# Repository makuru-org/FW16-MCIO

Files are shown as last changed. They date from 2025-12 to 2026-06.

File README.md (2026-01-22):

<!--
# Usecase
This is the source files needed to easily create an Framework 16 to MCIO expansion bay, so one can add a external GPU to the FW 16.
# PCB Render
![](images/pcb.png)
# Schematics
![](/images/schematics.png)

# How to use
1. Order PCB by JLCPCB with the correct impedence matching. (pls create issue if confused or help needed)
2. Order ADT-link's MCIO to PCIe eGPU station with MCIO cable. (tested with F37C version)
3. Print repo's STD files with a 3D printer.

# License
My changes are licensed under: [https://cern-ohl.web.cern.ch/](CERN-OHL-S).

The plain PCB template is I believe the https://github.com/jyancat/ExpansionBay under CC BY 4.0.

This is a fork of the [https://github.com/Terrails/FW16-OCuLink](Terrails), work as of writting this, it is not licensed, IE under **UNLICENSED**.
--!>
# STILL IN DEV

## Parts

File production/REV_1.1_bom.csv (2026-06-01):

Designator | Footprint | Quantity | Value | LCSC Part #
C1, C2, C4, C5 | C_Wurth_WCAP-CSGP-0201 | 4 | 0201_885012004001 | C20040658
C3 | C_Wurth_WCAP-CSGP-0402 | 1 | 0402_885012105020 | C6839882
EEPROM1 | SOP8_ROM | 1 | BR24L32F-WE2 | C253183
FAN1, FAN2 | AMPHENOL_F3311A7H121004E200 | 2 | F3311A7H121004E200 | C3169422
MCIO1 | AMPHENOL_G97R22312HR | 1 | G97R22312HR | C4499806
R1, R2 | R_Wurth_WRIS-RSKS-0402 | 2 | 0402_560112110088 | 560112110088
R10, R3, R4, R5, R6, R7, R8, R9 | R_Wurth_WRIS-RSKS-0402 | 8 | 0402_560112110001 | C22463254
U1 | VDFN8_NNC_MCH | 1 | SY75602ATWL-TR | C3613417

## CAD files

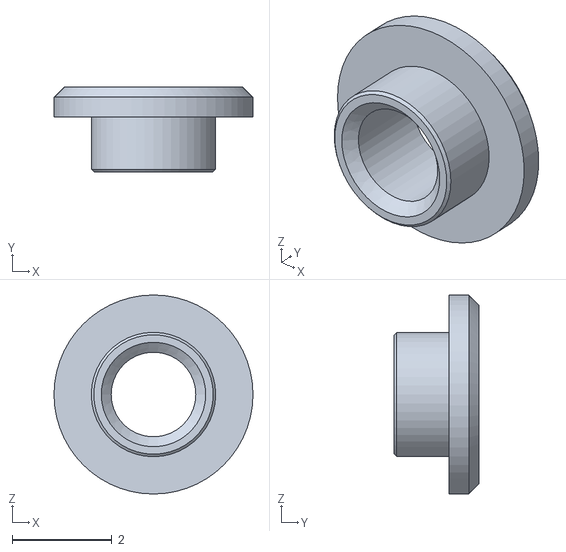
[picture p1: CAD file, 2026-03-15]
components/nut/Unnamed-IFGP6_UMA_IO_BOARD_ASM001SOLID004.obj
4.00 x 1.70 x 4.00

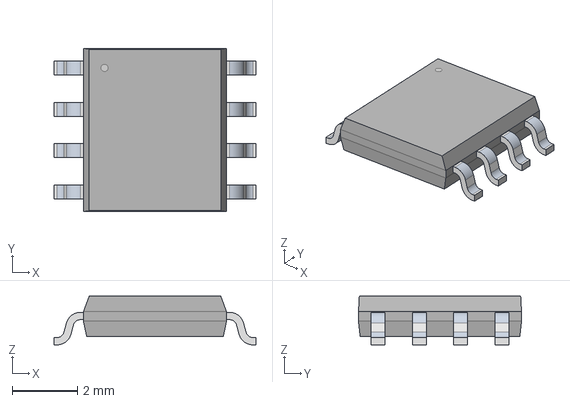
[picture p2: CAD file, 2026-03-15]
components/eeprom/SOP8_ROM.iges
6.20 x 5.00 x 1.50 mm

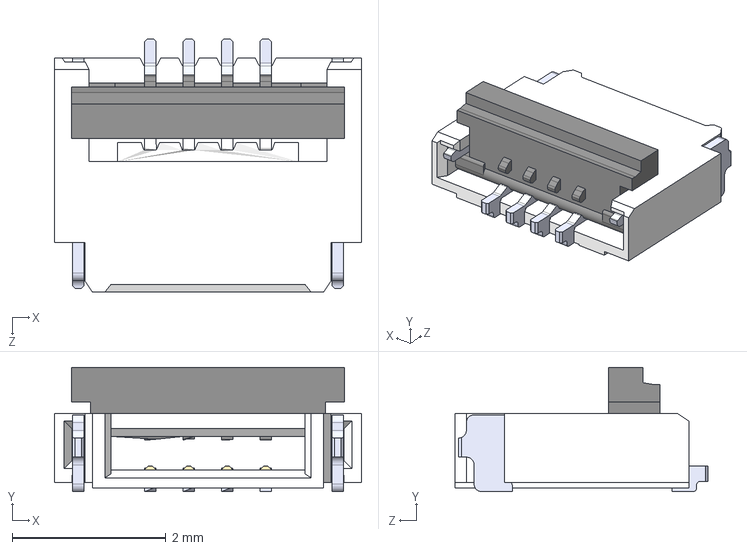
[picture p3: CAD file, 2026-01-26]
components/fan-connector/F3311A7H121004E200.step
4.00 x 1.62 x 3.30 mm

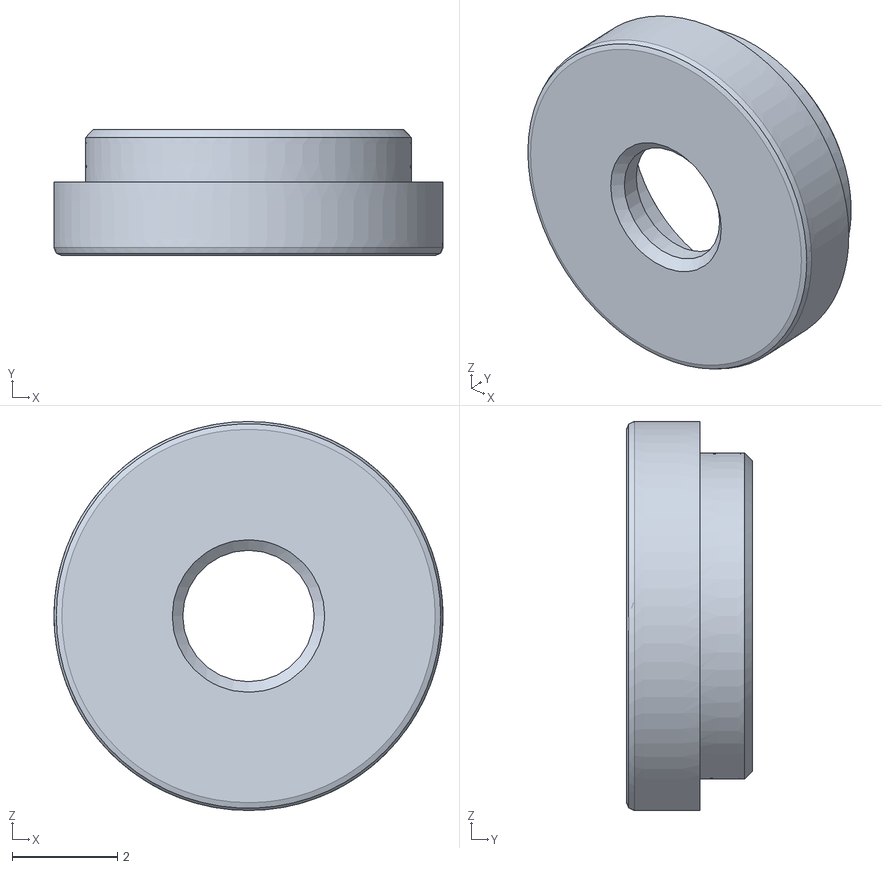
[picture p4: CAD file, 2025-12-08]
components/fw_expansion_bay_standoff_1_long.stl
7.40 x 2.40 x 7.40

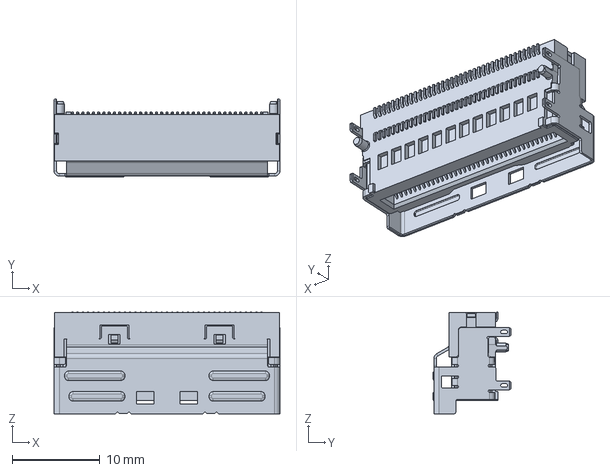
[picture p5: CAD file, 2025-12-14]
components/mcio-connector/G97R22312HR.step
25.8 x 8.94 x 11.6 mm

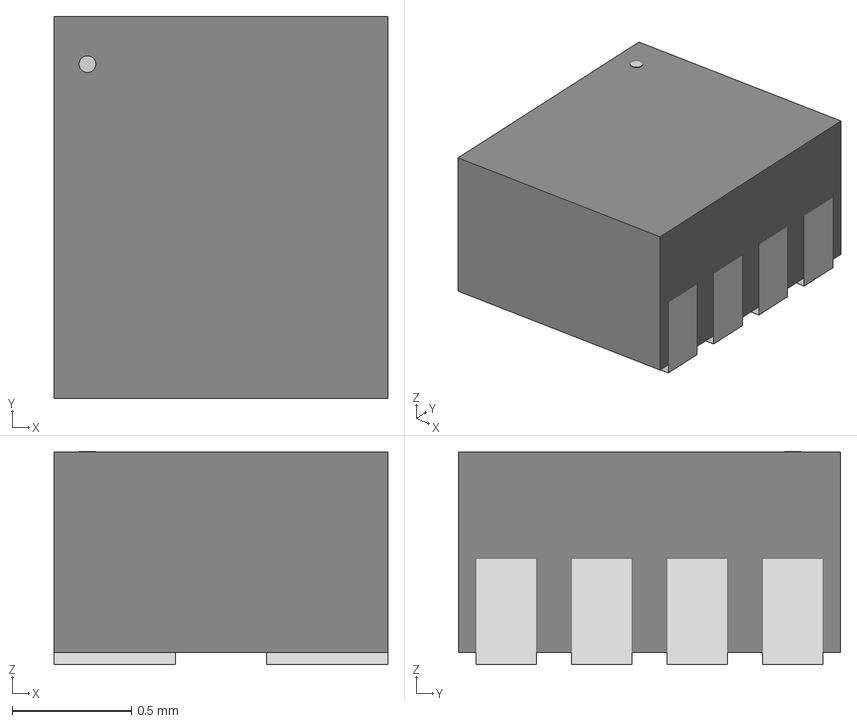
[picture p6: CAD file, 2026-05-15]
components/pcie-clk-buffer/VDFN8_NNC_MCH.iges
1.40 x 1.60 x 0.892 mm

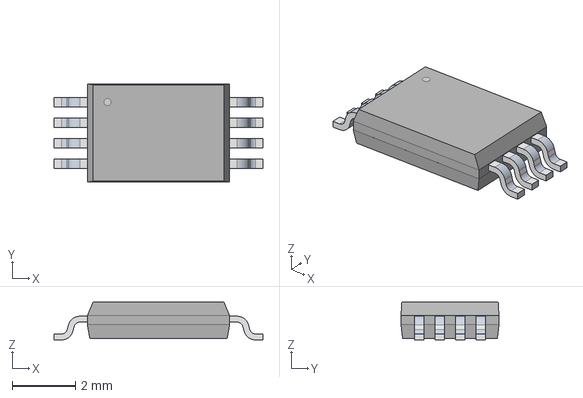
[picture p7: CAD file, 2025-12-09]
components/eeprom/TSSOP8_4P5X3P1X0P65_STM.iges
6.60 x 3.10 x 1.20 mm

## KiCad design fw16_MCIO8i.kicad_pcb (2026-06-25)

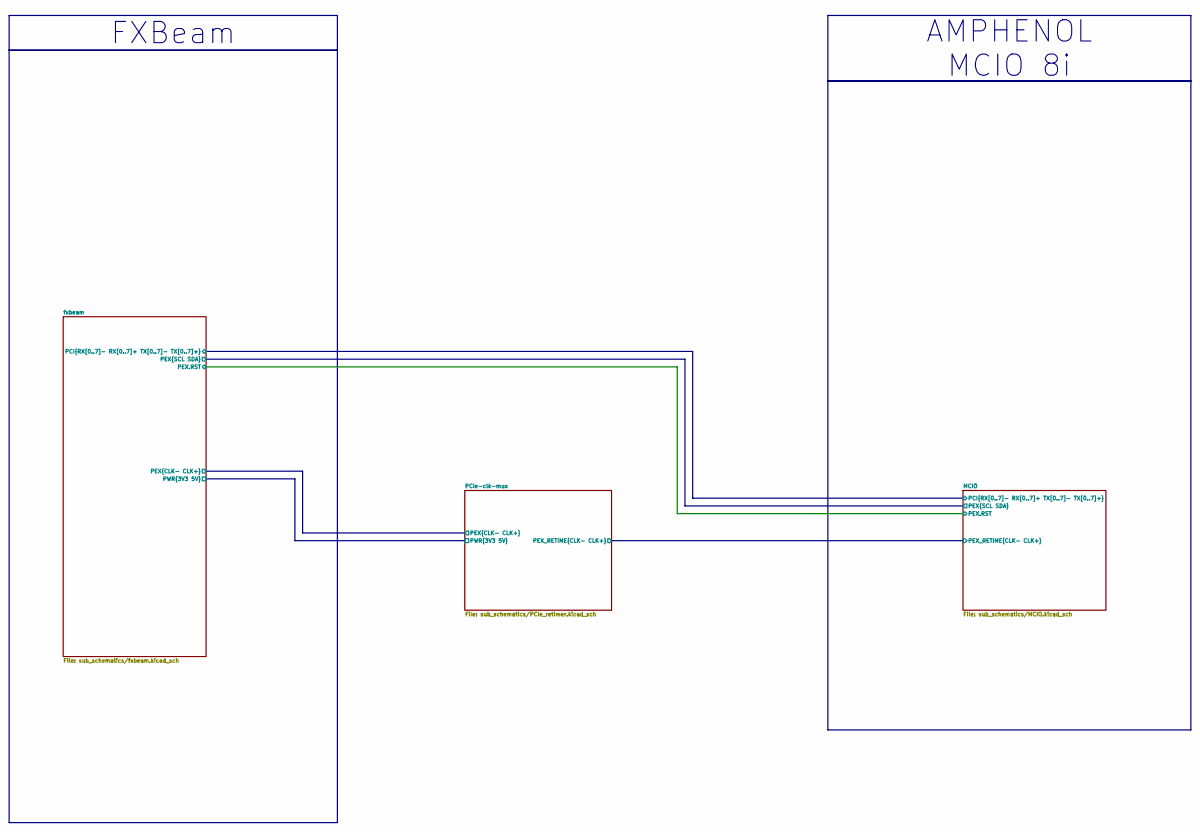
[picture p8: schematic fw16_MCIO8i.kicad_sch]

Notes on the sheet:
AMPHENOL MCIO 8i
FXBeam

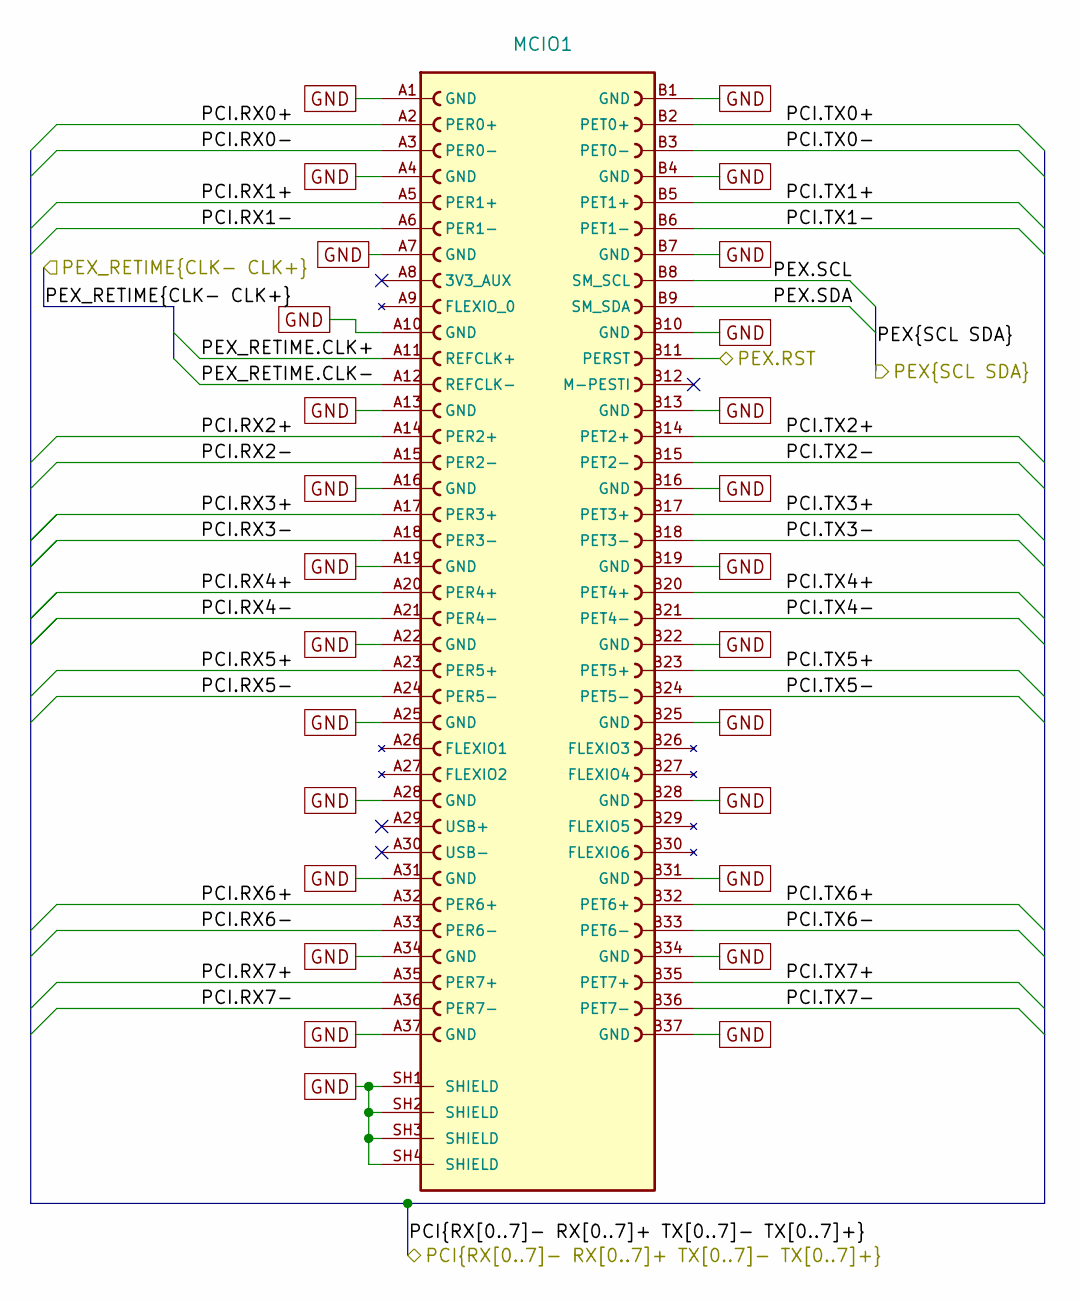
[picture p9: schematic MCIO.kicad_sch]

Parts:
MCIO1: G97R22312HR; AMPHENOL_G97R22312HR; PARTREV AX16; JLCPCB Part # C4499806

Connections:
/MCIO/PCI.RX0+: MCIO1.A2 (PER0+); also elsewhere on the board
/MCIO/PCI.RX0-: MCIO1.A3 (PER0-); also elsewhere on the board
/MCIO/PCI.RX1+: MCIO1.A5 (PER1+); also elsewhere on the board
/MCIO/PCI.RX1-: MCIO1.A6 (PER1-); also elsewhere on the board
/MCIO/PCI.RX2+: MCIO1.A14 (PER2+); also elsewhere on the board
/MCIO/PCI.RX2-: MCIO1.A15 (PER2-); also elsewhere on the board
/MCIO/PCI.RX3+: MCIO1.A17 (PER3+); also elsewhere on the board
/MCIO/PCI.RX3-: MCIO1.A18 (PER3-); also elsewhere on the board
/MCIO/PCI.RX4+: MCIO1.A20 (PER4+); also elsewhere on the board
/MCIO/PCI.RX4-: MCIO1.A21 (PER4-); also elsewhere on the board
/MCIO/PCI.RX5+: MCIO1.A23 (PER5+); also elsewhere on the board
/MCIO/PCI.RX5-: MCIO1.A24 (PER5-); also elsewhere on the board
/MCIO/PCI.RX6+: MCIO1.A32 (PER6+); also elsewhere on the board
/MCIO/PCI.RX6-: MCIO1.A33 (PER6-); also elsewhere on the board
/MCIO/PCI.RX7+: MCIO1.A35 (PER7+); also elsewhere on the board
/MCIO/PCI.RX7-: MCIO1.A36 (PER7-); also elsewhere on the board
/MCIO/PCI.TX0+: MCIO1.B2 (PET0+); also elsewhere on the board
/MCIO/PCI.TX0-: MCIO1.B3 (PET0-); also elsewhere on the board
/MCIO/PCI.TX1+: MCIO1.B5 (PET1+); also elsewhere on the board
/MCIO/PCI.TX1-: MCIO1.B6 (PET1-); also elsewhere on the board
/MCIO/PCI.TX2+: MCIO1.B14 (PET2+); also elsewhere on the board
/MCIO/PCI.TX2-: MCIO1.B15 (PET2-); also elsewhere on the board
/MCIO/PCI.TX3+: MCIO1.B17 (PET3+); also elsewhere on the board
/MCIO/PCI.TX3-: MCIO1.B18 (PET3-); also elsewhere on the board
/MCIO/PCI.TX4+: MCIO1.B20 (PET4+); also elsewhere on the board
/MCIO/PCI.TX4-: MCIO1.B21 (PET4-); also elsewhere on the board
/MCIO/PCI.TX5+: MCIO1.B23 (PET5+); also elsewhere on the board
/MCIO/PCI.TX5-: MCIO1.B24 (PET5-); also elsewhere on the board
/MCIO/PCI.TX6+: MCIO1.B32 (PET6+); also elsewhere on the board
/MCIO/PCI.TX6-: MCIO1.B33 (PET6-); also elsewhere on the board
/MCIO/PCI.TX7+: MCIO1.B35 (PET7+); also elsewhere on the board
/MCIO/PCI.TX7-: MCIO1.B36 (PET7-); also elsewhere on the board
/MCIO/PEX.SCL: MCIO1.B8 (SM_SCL); also elsewhere on the board
/MCIO/PEX.SDA: MCIO1.B9 (SM_SDA); also elsewhere on the board
/MCIO/PEX_RETIME.CLK+: MCIO1.A11 (REFCLK+); also elsewhere on the board
/MCIO/PEX_RETIME.CLK-: MCIO1.A12 (REFCLK-); also elsewhere on the board
/fxbeam/PEX.RST: MCIO1.B11 (PERST); also elsewhere on the board
GND: MCIO1.A1 (GND), MCIO1.A4 (GND), MCIO1.A7 (GND), MCIO1.A10 (GND), MCIO1.A13 (GND), MCIO1.A16 (GND), MCIO1.A19 (GND), MCIO1.A22 (GND), MCIO1.A25 (GND), MCIO1.A28 (GND), MCIO1.A31 (GND), MCIO1.A34 (GND), MCIO1.A37 (GND), MCIO1.B1 (GND), MCIO1.B4 (GND), MCIO1.B7 (GND), MCIO1.B10 (GND), MCIO1.B13 (GND), MCIO1.B16 (GND), MCIO1.B19 (GND), MCIO1.B22 (GND), MCIO1.B25 (GND), MCIO1.B28 (GND), MCIO1.B31 (GND), MCIO1.B34 (GND), MCIO1.B37 (GND), MCIO1.SH1 (SHIELD), MCIO1.SH2 (SHIELD), MCIO1.SH3 (SHIELD), MCIO1.SH4 (SHIELD); also elsewhere on the board

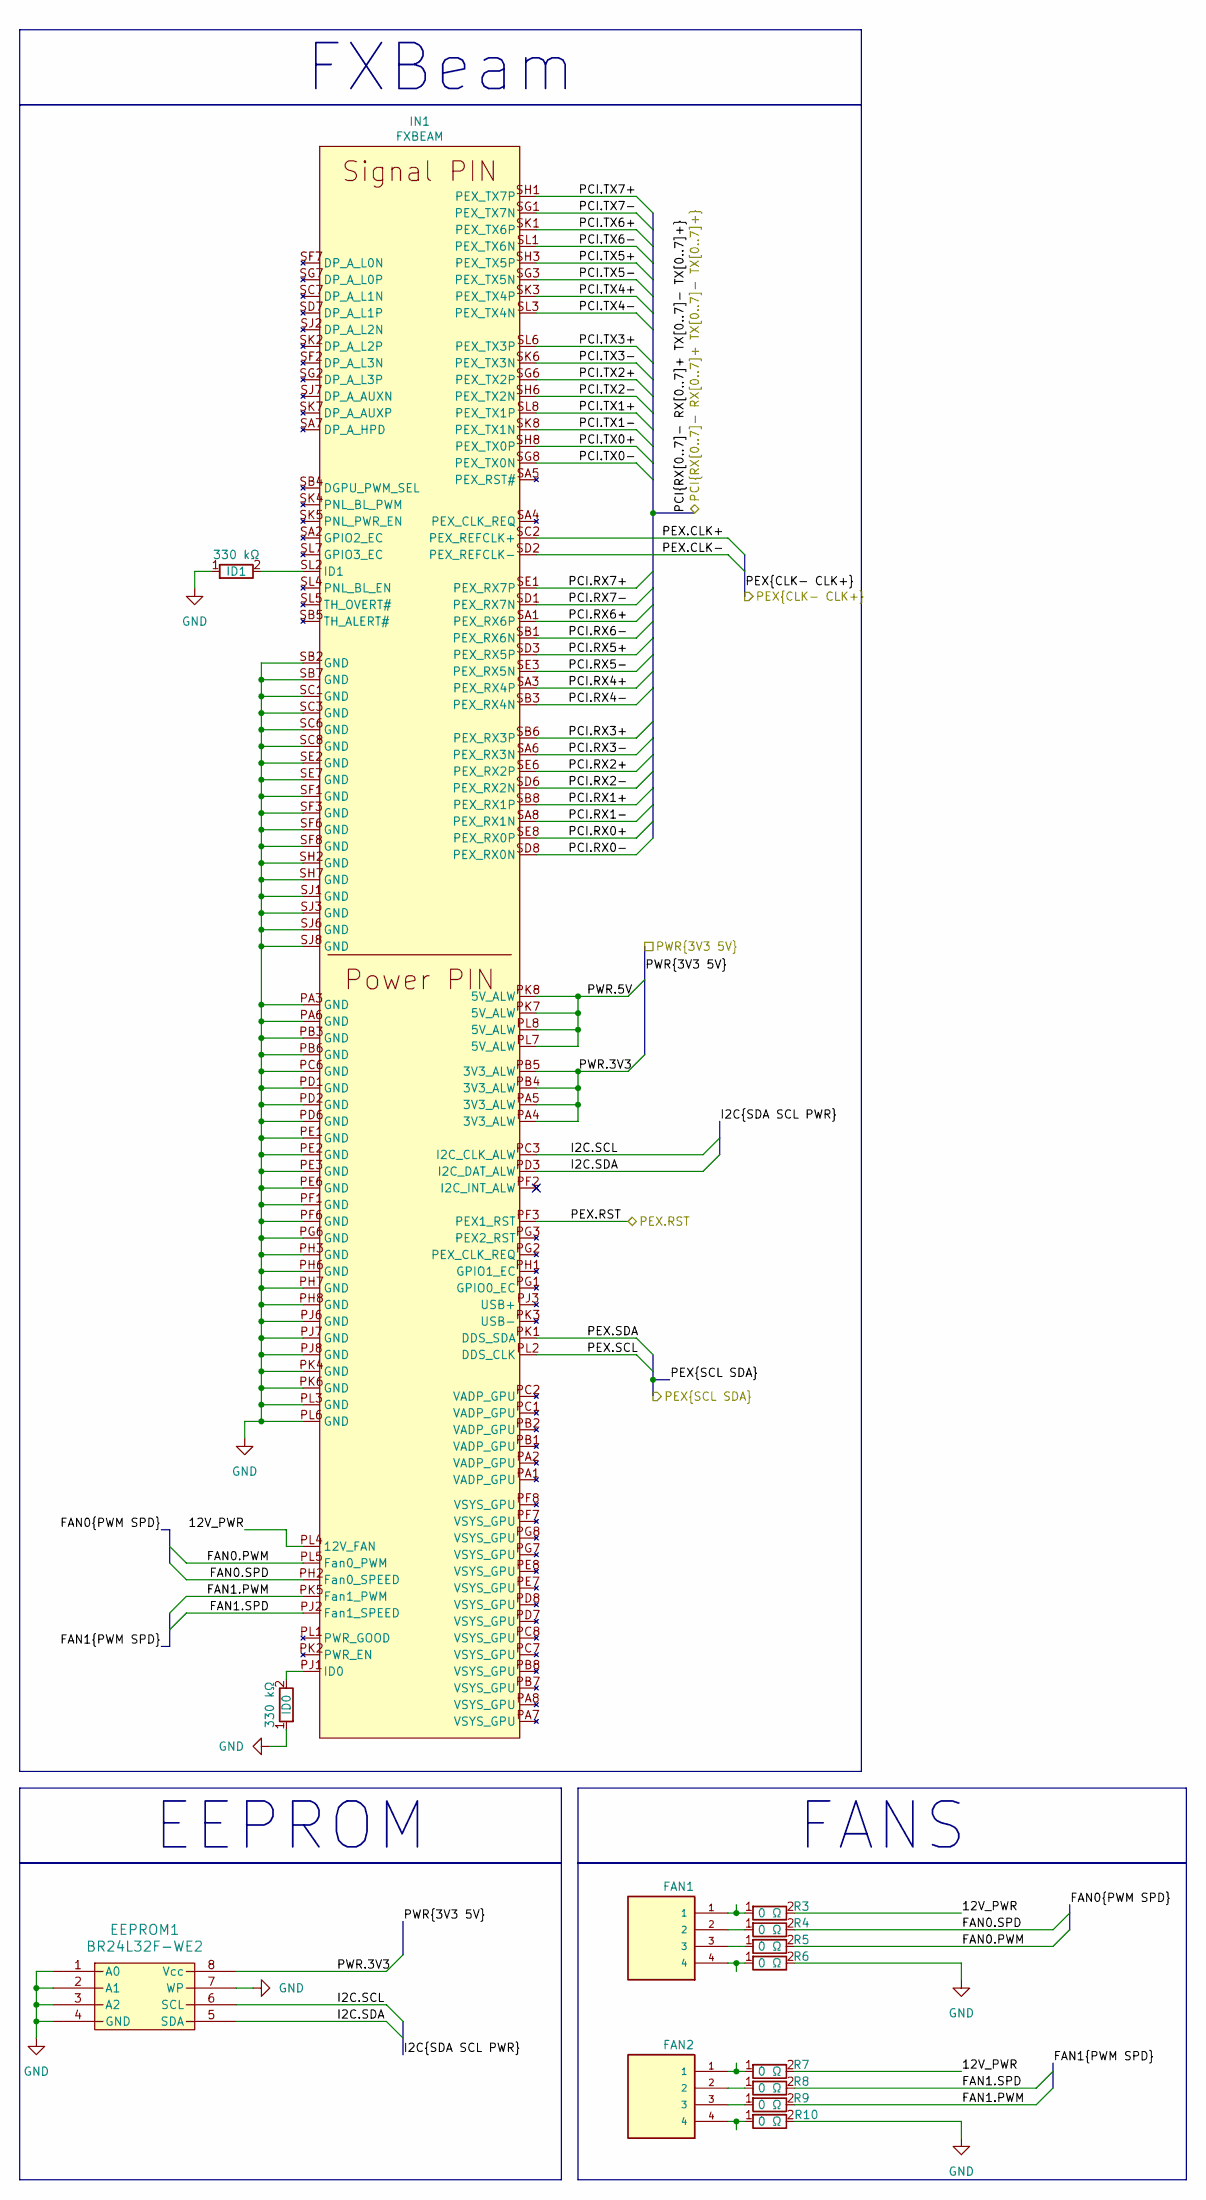
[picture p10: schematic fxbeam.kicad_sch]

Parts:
EEPROM1: BR24L32F-WE2; SOP8_ROM; MPN BR24L32F-WE2; JLCPCB Part # C253183
FAN1, FAN2: F3311A7H121004E200; AMPHENOL_F3311A7H121004E200; PARTREV A; JLCPCB Part # C3169422
ID0, ID1: 1206_R_560112132036; R_Wurth_WRIS-RSKS-1206_W; Part Number 560112132036; JLCPCB Part # C26798316
IN1: FXBEAM
R3, R4, R5, R6, R7, R8, R9, R10: 1206_R_560112132007; R_Wurth_WRIS-RSKS-1206_W; Part Number 560112132007; JLCPCB Part # C25268462

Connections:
/MCIO/PCI.RX0+: IN1.SE8 (PEX_RX0P); also elsewhere on the board
/MCIO/PCI.RX0-: IN1.SD8 (PEX_RX0N); also elsewhere on the board
/MCIO/PCI.RX1+: IN1.SB8 (PEX_RX1P); also elsewhere on the board
/MCIO/PCI.RX1-: IN1.SA8 (PEX_RX1N); also elsewhere on the board
/MCIO/PCI.RX2+: IN1.SE6 (PEX_RX2P); also elsewhere on the board
/MCIO/PCI.RX2-: IN1.SD6 (PEX_RX2N); also elsewhere on the board
/MCIO/PCI.RX3+: IN1.SB6 (PEX_RX3P); also elsewhere on the board
/MCIO/PCI.RX3-: IN1.SA6 (PEX_RX3N); also elsewhere on the board
/MCIO/PCI.RX4+: IN1.SA3 (PEX_RX4P); also elsewhere on the board
/MCIO/PCI.RX4-: IN1.SB3 (PEX_RX4N); also elsewhere on the board
/MCIO/PCI.RX5+: IN1.SD3 (PEX_RX5P); also elsewhere on the board
/MCIO/PCI.RX5-: IN1.SE3 (PEX_RX5N); also elsewhere on the board
/MCIO/PCI.RX6+: IN1.SA1 (PEX_RX6P); also elsewhere on the board
/MCIO/PCI.RX6-: IN1.SB1 (PEX_RX6N); also elsewhere on the board
/MCIO/PCI.RX7+: IN1.SE1 (PEX_RX7P); also elsewhere on the board
/MCIO/PCI.RX7-: IN1.SD1 (PEX_RX7N); also elsewhere on the board
/MCIO/PCI.TX0+: IN1.SH8 (PEX_TX0P); also elsewhere on the board
/MCIO/PCI.TX0-: IN1.SG8 (PEX_TX0N); also elsewhere on the board
/MCIO/PCI.TX1+: IN1.SL8 (PEX_TX1P); also elsewhere on the board
/MCIO/PCI.TX1-: IN1.SK8 (PEX_TX1N); also elsewhere on the board
/MCIO/PCI.TX2+: IN1.SG6 (PEX_TX2P); also elsewhere on the board
/MCIO/PCI.TX2-: IN1.SH6 (PEX_TX2N); also elsewhere on the board
/MCIO/PCI.TX3+: IN1.SL6 (PEX_TX3P); also elsewhere on the board
/MCIO/PCI.TX3-: IN1.SK6 (PEX_TX3N); also elsewhere on the board
/MCIO/PCI.TX4+: IN1.SK3 (PEX_TX4P); also elsewhere on the board
/MCIO/PCI.TX4-: IN1.SL3 (PEX_TX4N); also elsewhere on the board
/MCIO/PCI.TX5+: IN1.SH3 (PEX_TX5P); also elsewhere on the board
/MCIO/PCI.TX5-: IN1.SG3 (PEX_TX5N); also elsewhere on the board
/MCIO/PCI.TX6+: IN1.SK1 (PEX_TX6P); also elsewhere on the board
/MCIO/PCI.TX6-: IN1.SL1 (PEX_TX6N); also elsewhere on the board
/MCIO/PCI.TX7+: IN1.SH1 (PEX_TX7P); also elsewhere on the board
/MCIO/PCI.TX7-: IN1.SG1 (PEX_TX7N); also elsewhere on the board
/MCIO/PEX.SCL: IN1.PL2 (DDS_CLK); also elsewhere on the board
/MCIO/PEX.SDA: IN1.PK1 (DDS_SDA); also elsewhere on the board
/PCIe-clk-mux/PEX.CLK+: IN1.SC2 (PEX_REFCLK+); also elsewhere on the board
/PCIe-clk-mux/PEX.CLK-: IN1.SD2 (PEX_REFCLK-); also elsewhere on the board
/PCIe-clk-mux/PWR.3V3: EEPROM1.8 (Vcc), IN1.PA4 (3V3_ALW), IN1.PA5 (3V3_ALW), IN1.PB4 (3V3_ALW), IN1.PB5 (3V3_ALW); also elsewhere on the board
/PCIe-clk-mux/PWR.5V: IN1.PK7 (5V_ALW), IN1.PK8 (5V_ALW), IN1.PL7 (5V_ALW), IN1.PL8 (5V_ALW)
/fxbeam/12V_PWR: IN1.PL4 (12V_FAN), R3.2, R7.2
/fxbeam/FAN0.PWM: IN1.PL5 (Fan0_PWM), R5.2
/fxbeam/FAN0.SPD: IN1.PH2 (Fan0_SPEED), R4.2
/fxbeam/FAN1.PWM: IN1.PK5 (Fan1_PWM), R9.2
/fxbeam/FAN1.SPD: IN1.PJ2 (Fan1_SPEED), R8.2
/fxbeam/I2C.SCL: EEPROM1.6 (SCL), IN1.PC3 (I2C_CLK_ALW)
/fxbeam/I2C.SDA: EEPROM1.5 (SDA), IN1.PD3 (I2C_DAT_ALW)
/fxbeam/PEX.RST: IN1.PF3 (PEX1_RST); also elsewhere on the board
GND: EEPROM1.1 (A0), EEPROM1.2 (A1), EEPROM1.3 (A2), EEPROM1.4 (GND), EEPROM1.7 (WP), ID0.1, ID1.1, IN1.PA3 (GND), IN1.PA6 (GND), IN1.PB3 (GND), IN1.PB6 (GND), IN1.PC6 (GND), IN1.PD1 (GND), IN1.PD2 (GND), IN1.PD6 (GND), IN1.PE1 (GND), IN1.PE2 (GND), IN1.PE3 (GND), IN1.PE6 (GND), IN1.PF1 (GND), IN1.PF6 (GND), IN1.PG6 (GND), IN1.PH3 (GND), IN1.PH6 (GND), IN1.PH7 (GND), IN1.PH8 (GND), IN1.PJ6 (GND), IN1.PJ7 (GND), IN1.PJ8 (GND), IN1.PK4 (GND), IN1.PK6 (GND), IN1.PL3 (GND), IN1.PL6 (GND), IN1.SB2 (GND), IN1.SB7 (GND), IN1.SC1 (GND), IN1.SC3 (GND), IN1.SC6 (GND), IN1.SC8 (GND), IN1.SE2 (GND), IN1.SE7 (GND), IN1.SF1 (GND), IN1.SF3 (GND), IN1.SF6 (GND), IN1.SF8 (GND), IN1.SH2 (GND), IN1.SH7 (GND), IN1.SJ1 (GND), IN1.SJ3 (GND), IN1.SJ6 (GND), IN1.SJ8 (GND), R6.2, R10.2; also elsewhere on the board
unnamed: FAN1.1, R3.1
unnamed: FAN1.2, R4.1
unnamed: FAN1.3, R5.1
unnamed: FAN1.4, R6.1
unnamed: FAN2.1, R7.1
unnamed: FAN2.2, R8.1
unnamed: FAN2.3, R9.1
unnamed: FAN2.4, R10.1
unnamed: ID0.2, IN1.PJ1 (ID0)
unnamed: ID1.2, IN1.SL2 (ID1)

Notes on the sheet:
EEPROM
FANS
FXBeam

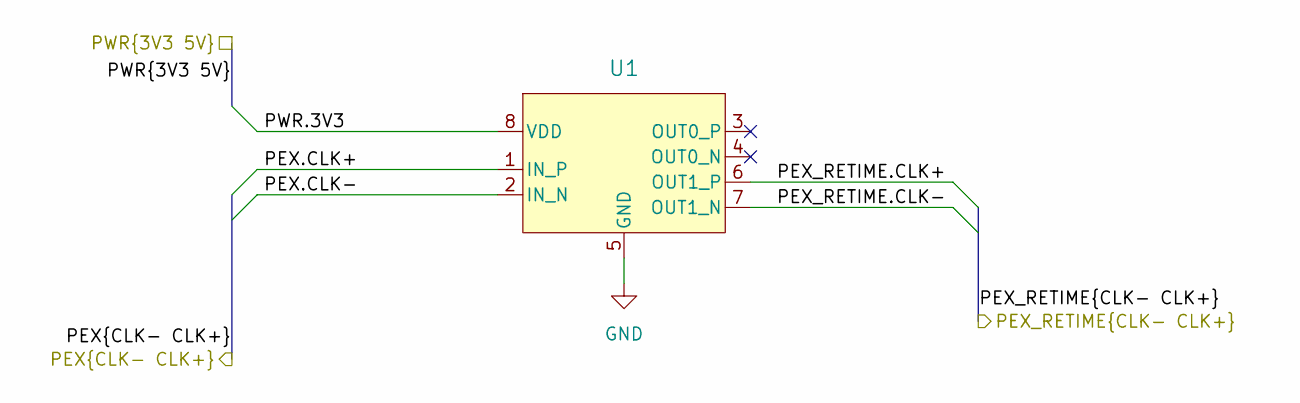
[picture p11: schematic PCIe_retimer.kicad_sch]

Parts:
U1: SY75602ATWL-TR; VDFN8_NNC_MCH; MPN SY75602ATWL-TR; JLCPCB Part # C3613417

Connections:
/MCIO/PEX_RETIME.CLK+: U1.6 (OUT1_P); also elsewhere on the board
/MCIO/PEX_RETIME.CLK-: U1.7 (OUT1_N); also elsewhere on the board
/PCIe-clk-mux/PEX.CLK+: U1.1 (IN_P); also elsewhere on the board
/PCIe-clk-mux/PEX.CLK-: U1.2 (IN_N); also elsewhere on the board
/PCIe-clk-mux/PWR.3V3: U1.8 (VDD); also elsewhere on the board
GND: U1.5 (GND); also elsewhere on the board

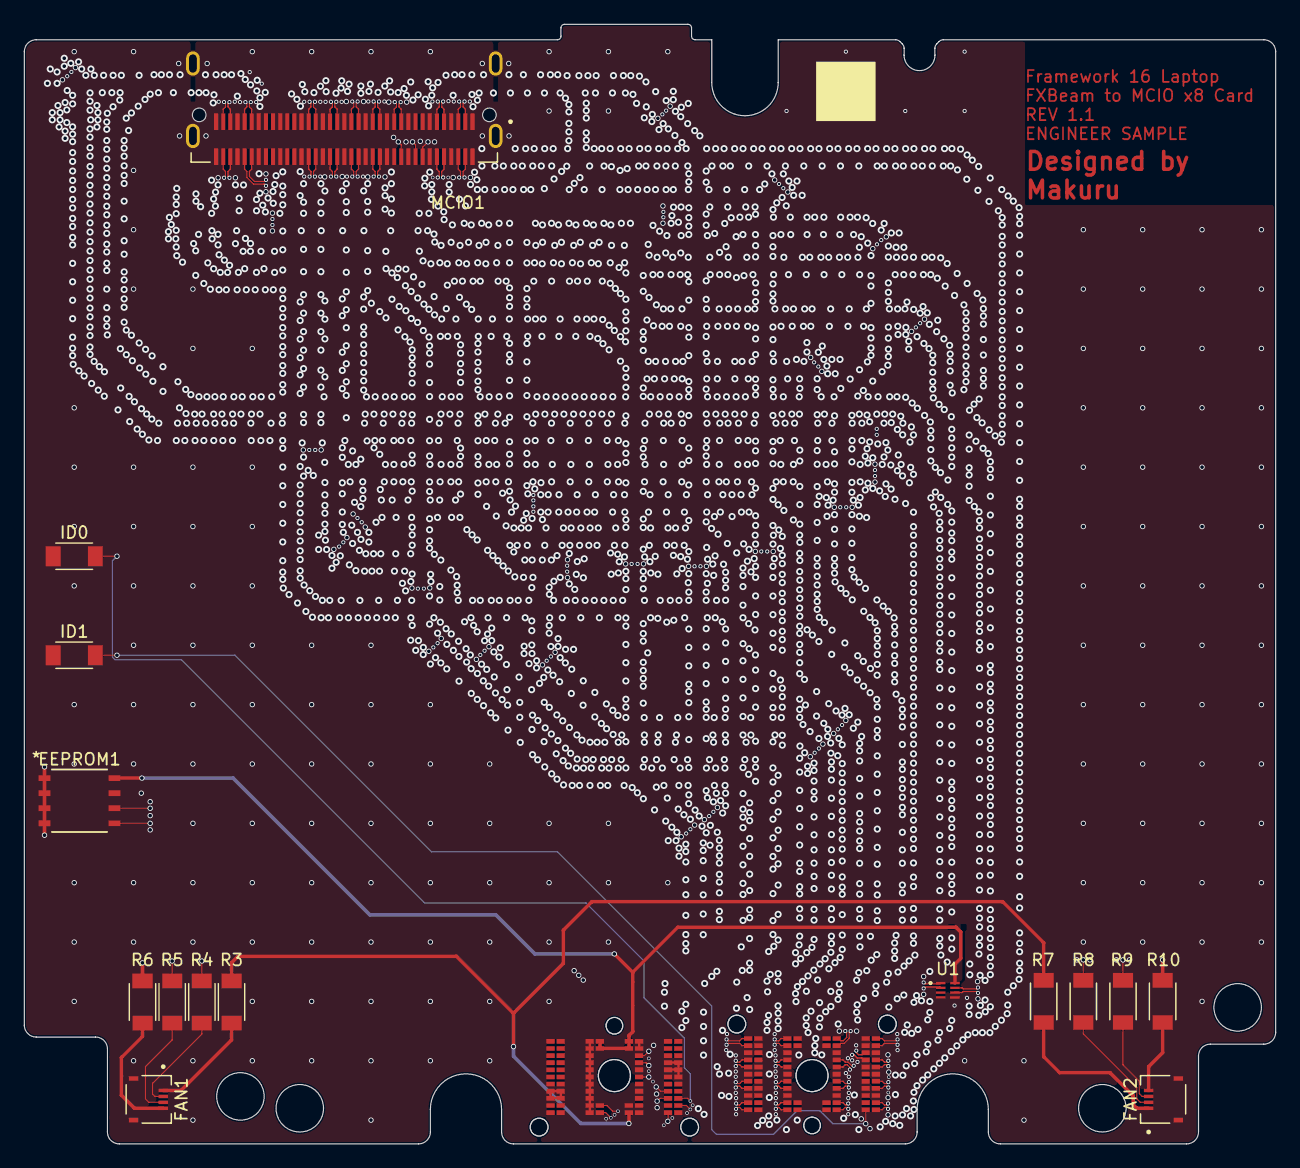
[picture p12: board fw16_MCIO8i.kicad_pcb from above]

Board: 6 copper layers, 105.4 x 94.3 mm, 16 parts (0 on the bottom side), 59 nets.

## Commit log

2025-12-07 Renamed project
    [fw16_MCIO8i.kicad_pcb, fw16_MCIO8i.kicad_sch]
2025-12-07 Imported MCIO connector
    [1731620131.stp]
2025-12-07 Connected MCIO on Schematics
    [fw16_MCIO8i.kicad_pcb, fw16_MCIO8i.kicad_sch]
2025-12-07 Changed naming to lowercase
    [fw16_MCIO8i.kicad_pcb, fw16_MCIO8i.kicad_sch]
2025-12-08 New fan connector
    [59453-041110EDHLF.step, fw16_MCIO8i.kicad_pcb, fw16_MCIO8i.kicad_sch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]
2025-12-12 Switched redriver
    [NJX0064A.iges, fw16_MCIO8i.kicad_pcb]
2025-12-16 changed parts
    [59453-041110EDHLF.step, F33D-1A7H1-E7C04.step, fw16_MCIO8i.kicad_pcb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]
2025-12-18 Rerouted fxbeam
    [fw16_MCIO8i.kicad_pcb, fw16_MCIO8i.kicad_sch]
2025-12-19 Fixed errors
    [fw16_MCIO8i.kicad_pcb, fw16_MCIO8i.kicad_sch]
2025-12-23 New routing
    [DPF20102711TR.step, fw16_MCIO8i.kicad_pcb, fw16_MCIO8i.kicad_sch]
2026-01-02 Removed pour on signal layers
    [fw16_MCIO8i.kicad_pcb]
2026-01-22 diodes and jumpers
    [ES15DLW.step, SS115LW.step, fw16_MCIO8i.kicad_pcb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]
2026-01-22 README and cleanup
    [fw16_MCIO8i.kicad_pcb, fw16_MCIO8i.kicad_sch]
2026-01-23 Skewing around
    [fw16_MCIO8i.kicad_pcb]
2026-01-26 MPN added and removed unedded diode
    [F3311A7H121004E200.step, F33D-1A7H1-E7C04.step, fw16_MCIO8i.kicad_pcb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]
2026-01-27 Switched capacitor
    [fw16_MCIO8i.kicad_pcb, fw16_MCIO8i.kicad_sch]
2026-02-08 Fixed skew and silkscreen
    [fw16_MCIO8i.kicad_pcb]
2026-02-09 MPN & LCSC
    [fw16_MCIO8i.kicad_pcb, fw16_MCIO8i.kicad_sch]
2026-03-15 Fixed EEPROM error
    [SOP8_ROM.iges, Unnamed-IFGP6_UMA_IO_BOARD_ASM001SOLID004.obj, fw16_MCIO8i.kicad_pcb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]
2026-03-28 Schematics fixed
    [fw16_MCIO8i.kicad_sch]
2026-03-28 Switched to large board
    [fw16_MCIO8i.kicad_pcb]
2026-04-01 PCIe redriver and buck converter
    [ACB0332A.stp, DBV0005A.iges, NJX0064A.iges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]
2026-04-02 Schematics revamped
    [MCIO.kicad_sch, PCIe-Retimer.kicad_sch, fw16_MCIO8i.kicad_pcb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]
2026-04-06 moved schematics
    [Altium\2026-04-05_14-00-00\2026-04-05_14-00-001.schdoc, DBV0005A.iges, DRC0010J.iges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]
2026-04-07 buck converter changes
    [ACB0332A.iges, ACB0332A.stp, Altium\2026-04-05_14-00-00\2026-04-05_14-00-001.schdoc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]
2026-04-08 buck converter
    [PCIe_retimer.kicad_sch, PCIe_retimer_power.kicad_sch, fw16_MCIO8i.kicad_sch]
2026-04-09 buck converter component
    [CAP_0805P_AVX.iges, CAP_1005_TDK.iges, CAP_2012_TDK.iges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]
2026-04-14 Added Inductors
    [DPF20102711TR.step, ES15DLW.step, G14B80121612HR.step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]
2026-04-14 Added resistors
2026-04-14 Added capacitors
    [PCIe_retimer_power.kicad_sch]
2026-04-15 Fixed typo
    [PCIe_retimer_power.kicad_sch]
2026-04-15 Working buck converter
    [PCIe_retimer_power.kicad_sch]
2026-04-17 changed 1.8V buck
    [LM43600_AVG.DSN, LM43600_TRANS.DSN, PCIe_retimer_power.kicad_sch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]
2026-04-19 Buck closer to recommended value
    [PCIe_retimer_power.kicad_sch, fw16_MCIO8i.kicad_pcb]
2026-04-19 PCIe shematic fix
    [MCIO.kicad_sch, PCIe_retimer.kicad_sch, PCIe_retimer_power.kicad_sch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]
2026-05-15 Switch to retimer for only clock
    [ACB0332A.iges, CAP_0805P_AVX.iges, CAP_1005_TDK.iges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]
2026-05-15 Fixed board dimensions
    [MCIO.kicad_sch, PCIe_retimer.kicad_sch, fw16_MCIO8i.kicad_pcb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]
2026-05-16 Fixed board stackup
    [fw16_MCIO8i.kicad_pcb]
2026-05-17 Routing small schematic fix
    [PCIe_retimer.kicad_sch, fw16_MCIO8i.kicad_pcb]
2026-05-18 Preparing order
    [PCIe_retimer.kicad_sch, fw16_MCIO8i.kicad_pcb, fxbeam.kicad_sch]
2026-05-18 adjusted cut layer
    [fw16_MCIO8i.kicad_pcb]
2026-05-19 changed impedence matching
    [fw16_MCIO8i.kicad_pcb]
2026-05-30 Order prepare
    [MCIO.kicad_sch, fw16_MCIO8i.kicad_pcb, fxbeam.kicad_sch]
2026-06-01 Order rev1.1
    [REV_1.0_bom-JLCPCB Assembly Order-JLCPCB Assembly Order.xls, REV_1.0_bom-JLCPCB Assembly Order.xls, REV_1.0_bom.csv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]
2026-06-24 Reskew changed skematics
    [MCIO.kicad_sch, PCIe_retimer.kicad_sch, VDFN8_NNC_MCH.iges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]
2026-06-25 updated kicad oot
    [PCIe_retimer.kicad_sch, fw16_MCIO8i.kicad_pcb, fxbeam.kicad_sch]
2026-06-25 Via fencing
    [fw16_MCIO8i.kicad_pcb]
2026-06-25 schematics fixup
    [PCIe_retimer.kicad_sch, fw16_MCIO8i.kicad_pcb, fxbeam.kicad_sch]
